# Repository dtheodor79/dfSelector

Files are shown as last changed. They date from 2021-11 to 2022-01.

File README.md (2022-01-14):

# Wireless DF selector
 The Wireless DF (WDF) selector allows users to boot an Amiga 500 from an internal or external drive. Instead of using a mechanical switch or multiple reset sequences to toggle between DF0 and DF1, WDF can be configured over a wireless connection. 
 
# Why bother?
Well, all this started because I don't like modifying my A500's precious case (like drilling to install a switch) 🙂. Also, I find more elegant using wireless commands to toggle between DF0 and DF1, than multiple resets 😎.
 
# Concept
The WDF concept is illustrated below: 

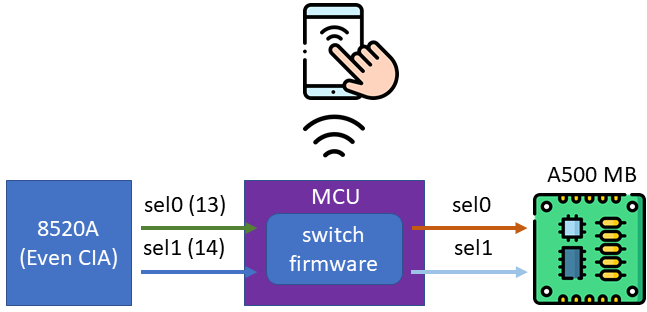
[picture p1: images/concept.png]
concept


Pins 13 (sel0) and 14 (sel1) from 8520A (even CIA) are connected to an MCU with wireless connection capability. Users can configure from an external device how these signals are forwarded to the A500 motherboard (MB), in order to select from which floppy drive the computer shall boot. 

# Demo video
Watch the video (https://youtu.be/IKIUbYo_S1U) 

# Implementation
The images below show three WDF 3D models that are implemented with an ESP32 MCU, enabling switch configuration over Bluetooth connections:

ESP32 "in front" of 8520A (click [here](https://www.pcbway.com/project/shareproject/Amiga_500_Wireless_DF_selector.html) to build one):

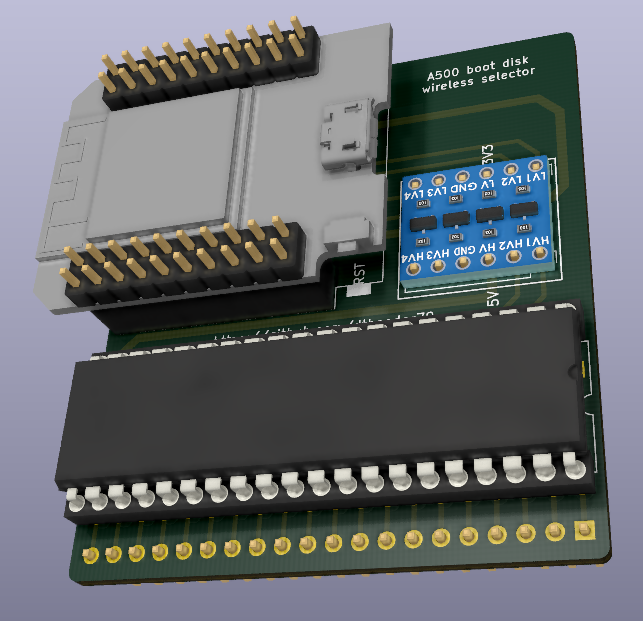
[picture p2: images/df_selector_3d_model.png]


ESP32 "behind" 8520A:

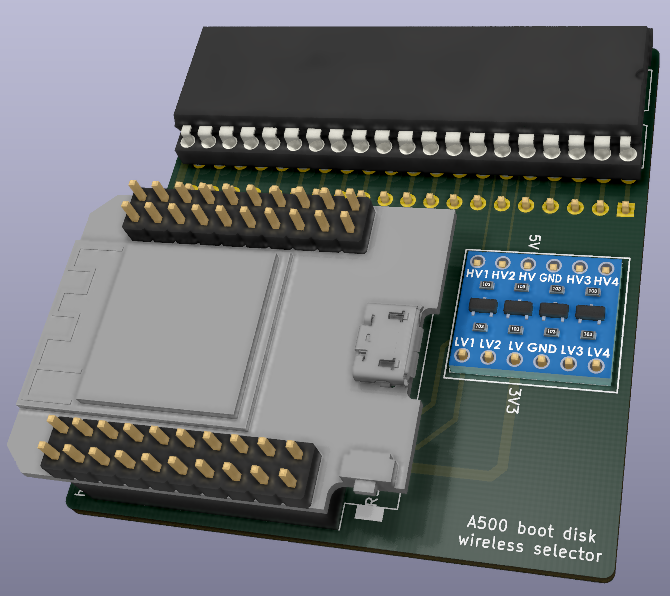
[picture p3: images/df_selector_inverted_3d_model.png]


ESP32 "stacked" on top of 8520A (click [here](https://www.pcbway.com/project/shareproject/Amiga_500_compact_wireless_DF_selector.html) to build one):

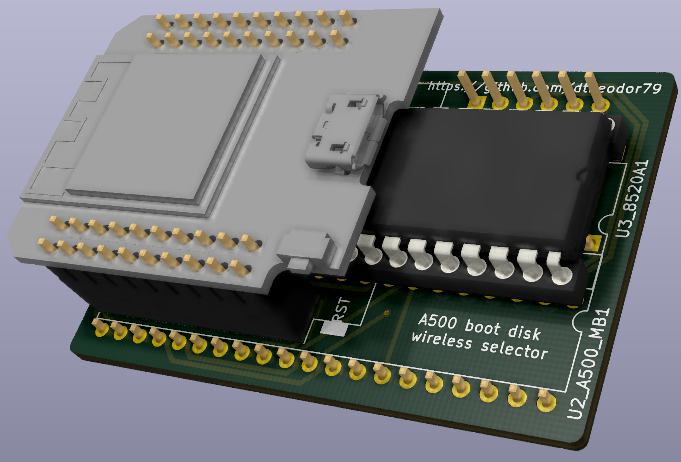
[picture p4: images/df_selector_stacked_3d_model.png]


A voltage convertor between 3.3V and 5V is used to allow communication between the ESP32 (3.3V) and the 8520A (5V). In addition, since the first WDF version (ESP32 "in front" of 8520A) is placed above the floppy ribbon cable connector of the A500, it requires long pin headers (such as the one below) to connect to the A500 MB:

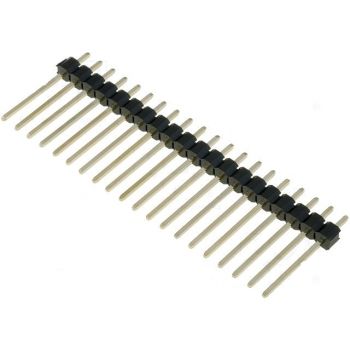
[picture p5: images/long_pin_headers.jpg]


# How to use the ESP32-based implementation
The current ESP32 firmware advertises a Bluetooth-enabled device with the name "A500 DF Selector". You will need another Bluetooth-enabled device to connect to the WDF and then send raw data for configuring the sel0 and sel1 switching. An easy way is to download a simple Bluetooth app to your smartphone that allows sending raw data to other devices. 

## Toggle DF1 as bootable:

* Make sure that there is no disk in DF0.
* Power-up the A500 and wait for few secs (e.g. 5).
* Scan for the "A500 DF Selector" device, and when found, connect to it.
* Send "df1".
* Power-down the A500 for a few secs.
* Power-up again, and now the A500 should boot from DF1.

## Toggle DF0 as bootable:

* Make sure that there is no disk (or adf image that will boot) in DF1.
* Power-up the A500 and wait for few secs (e.g. 5).
* Scan for the "A500 DF Selector" device, and when found, connect to it.
* Send "df0".
* Power-down the A500 for a few secs.
* Power-up again, and now the A500 should boot from DF0.

# Important notes
- All tests were carried out with a modified PC-floppy as DF0 and a Gotek emulator as DF1 (but jumper set to S0). As you can see in the demo video above, floppy selection could be done seamlessly without even restarting the A500 💣, by sending "df0" and "df1" commands when there was no floppy access. If you would like to try it, please be careful and always make sure before sending any command that there is no floppy access (don't blame me if there is any damage though 😛). 
- When DF0 is selected, the current firmware  
  - forwards sel0 (8520A) ➡️ sel0 (A500 MB)
  - sets sel1 (A500 MB) ➡️ HIGH
- When DF1 is selected, the current firmware  
  - forwards sel0 (8520A) ➡️ sel1 (A500 MB)
  - forwards sel1 (8520A) ➡️ sel0 (A500 MB)

Feel free to change how the firmware handles switching, so it suits to your configuration 😉.

# Pictures of the ESP32 implementation
Here are a few images of the final prototype on my A500.

WDF mounted above the floppy ribbon cable connector:

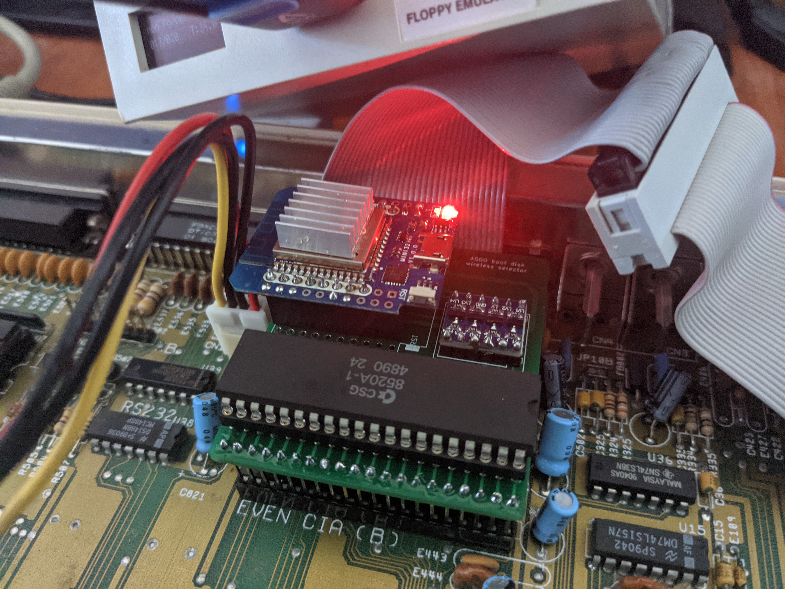
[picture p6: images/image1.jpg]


Loading Cannon Fodder from the Gotek emulator as DF1:

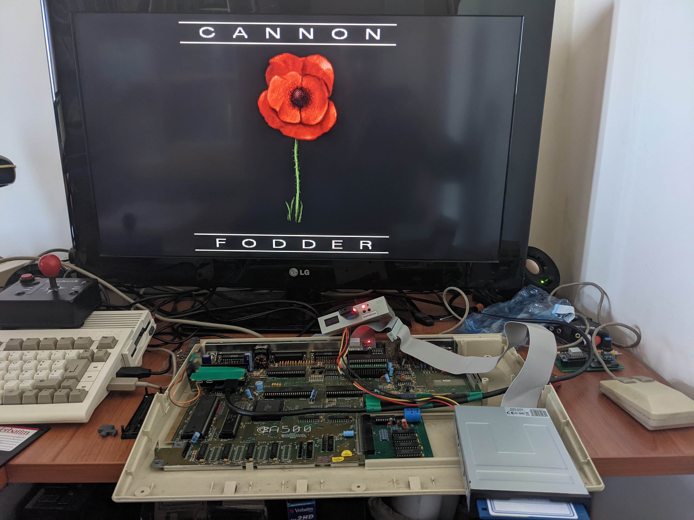
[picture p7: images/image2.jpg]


Another view of the WDF mounted above the floppy ribbon cable connector:

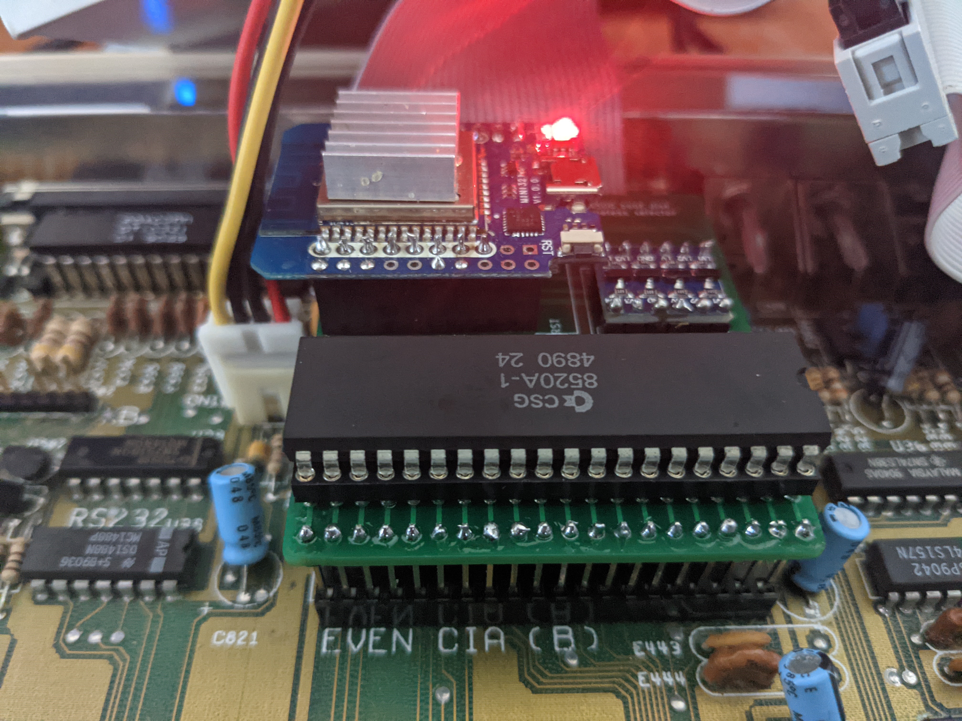
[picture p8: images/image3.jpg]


Gotek emulator connected externally:

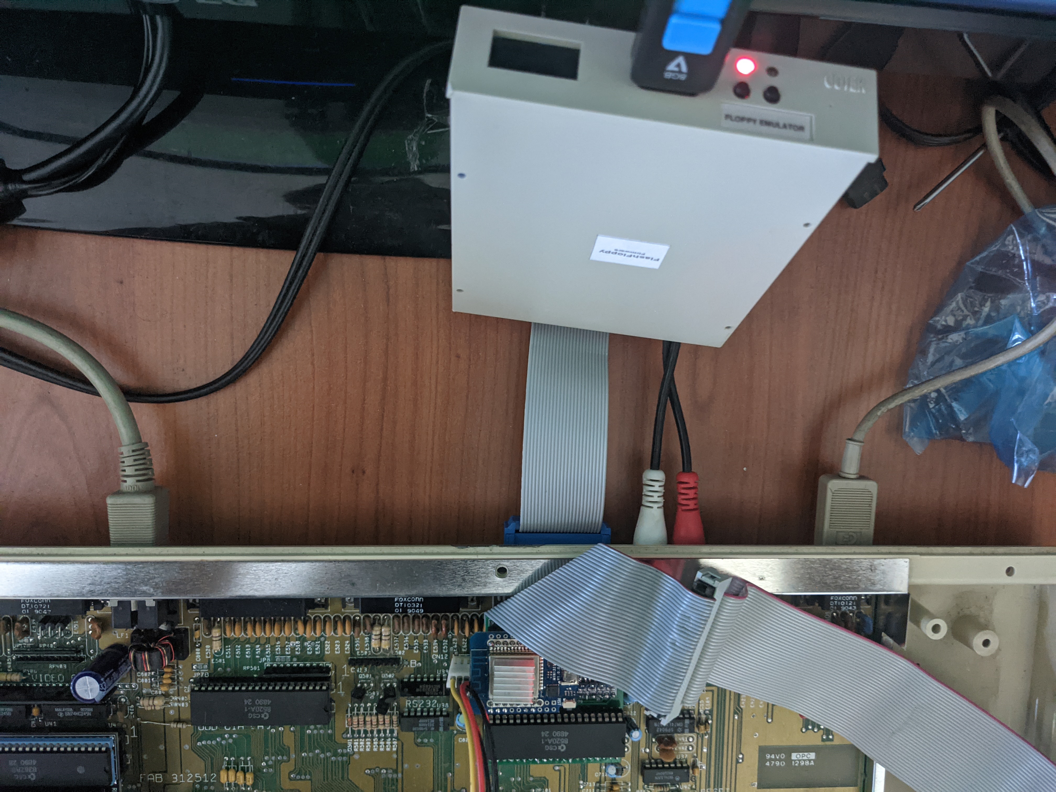
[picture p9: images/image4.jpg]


Hope you find it useful!! 😎

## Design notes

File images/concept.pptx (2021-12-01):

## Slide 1

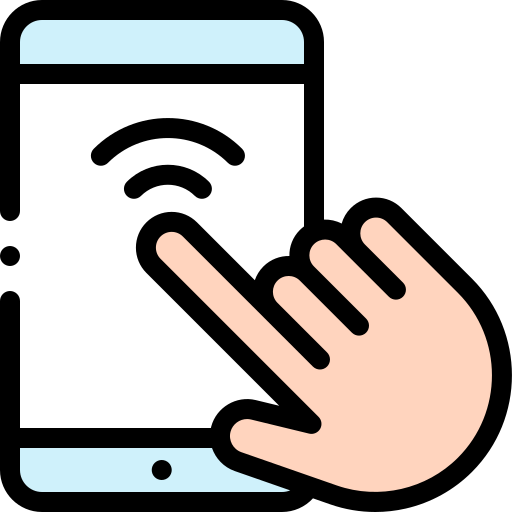
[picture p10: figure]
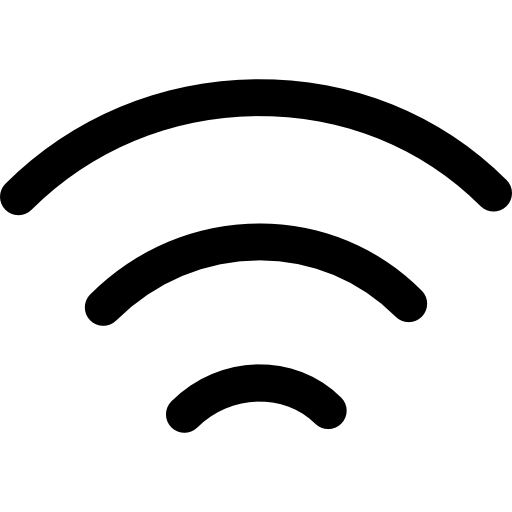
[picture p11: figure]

A500 MB

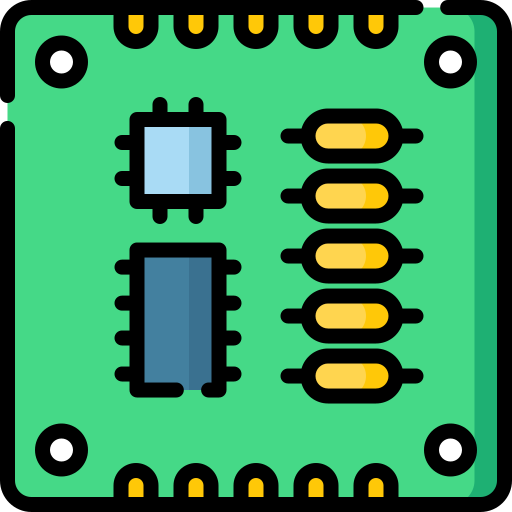
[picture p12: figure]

8520A
(Even CIA)

sel0 (13)

MCU

switch
firmware

sel0

sel1

sel1 (14)

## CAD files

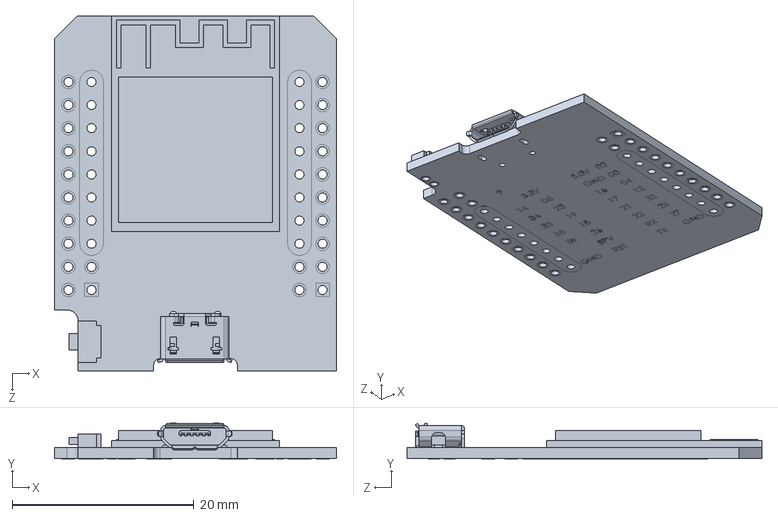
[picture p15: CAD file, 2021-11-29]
pcb/esp32 3d model/Wemos-Mini-D1-ESP32.SLDPRT
31.0 x 3.92 x 39.0 mm

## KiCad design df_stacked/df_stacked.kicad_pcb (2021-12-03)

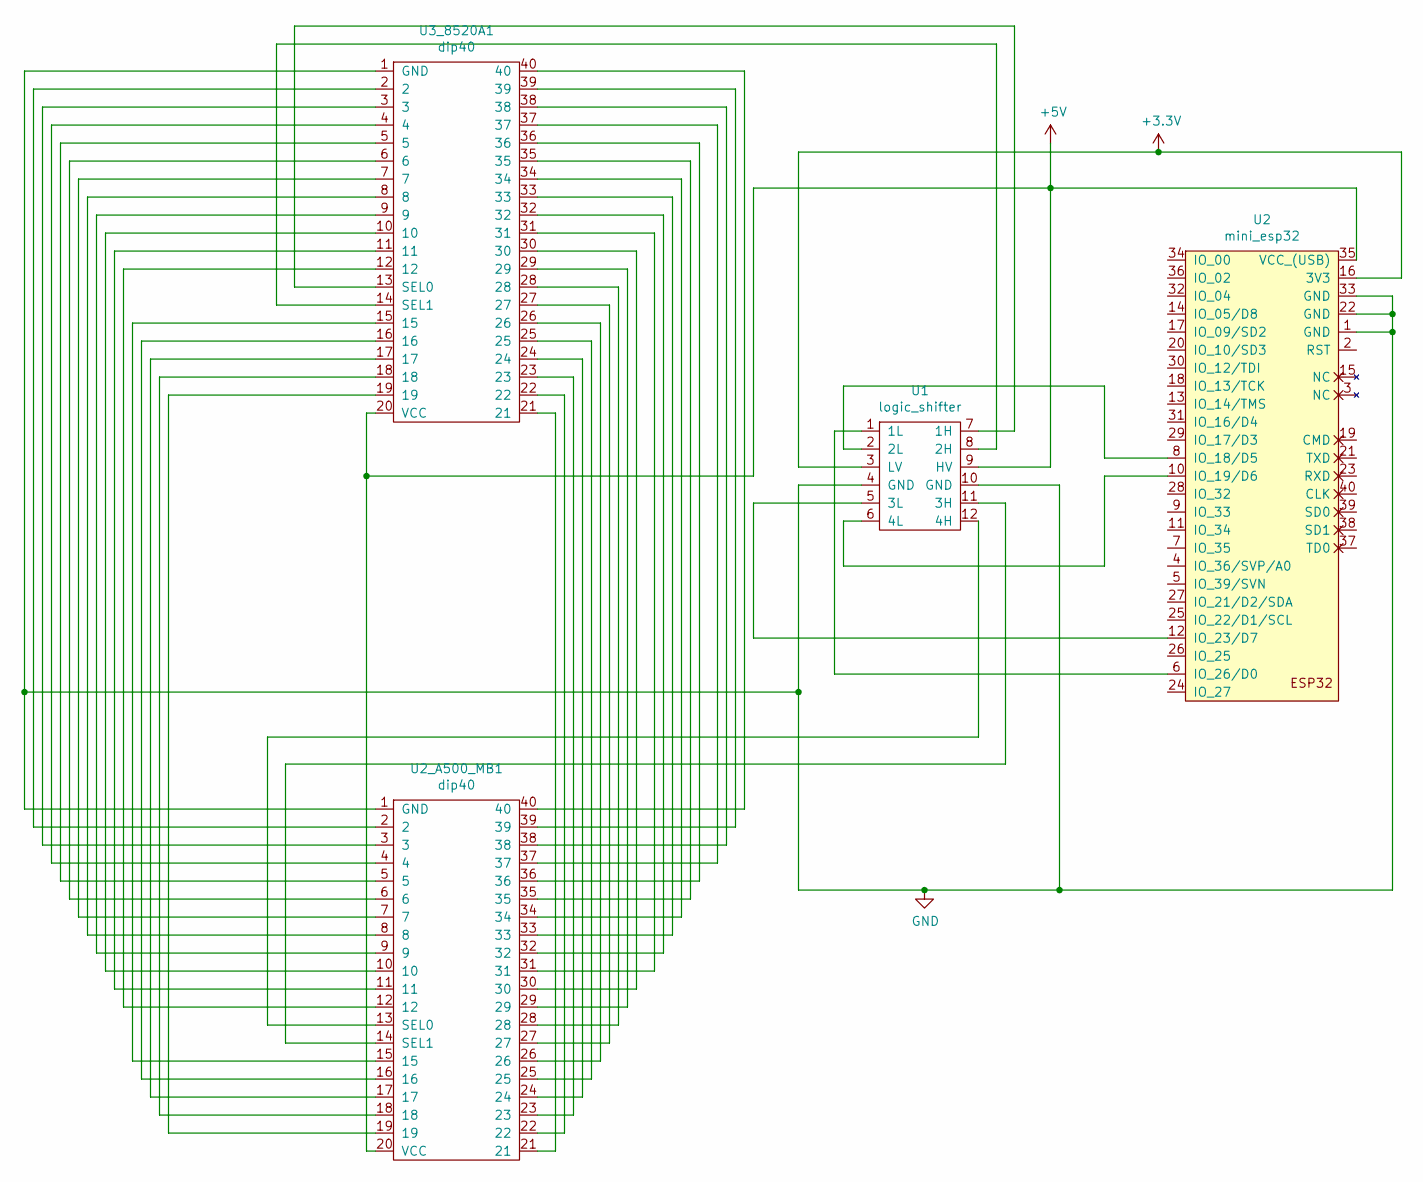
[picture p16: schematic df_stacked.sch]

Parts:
U1: logic_shifter; 4channel_logic_shifter
U2: mini_esp32; ESP32_mini
U2_A500_MB1, U3_8520A1: dip40; DIP-40_W15.24mm

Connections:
+3V3: U1.3 (LV), U2.16 (3V3)
+5V: U1.9 (HV), U2.35 (VCC_(USB)), U2_A500_MB1.20 (VCC), U3_8520A1.20 (VCC)
GND: U1.4 (GND), U1.10 (GND), U2.1 (GND), U2.22 (GND), U2.33 (GND), U2_A500_MB1.1 (GND), U3_8520A1.1 (GND)
unnamed: U1.1 (1L), U2.6 (IO_26/D0)
unnamed: U1.2 (2L), U2.8 (IO_18/D5)
unnamed: U1.5 (3L), U2.12 (IO_23/D7)
unnamed: U1.6 (4L), U2.10 (IO_19/D6)
unnamed: U1.7 (1H), U3_8520A1.13 (SEL0)
unnamed: U1.8 (2H), U3_8520A1.14 (SEL1)
unnamed: U1.11 (3H), U2_A500_MB1.14 (SEL1)
unnamed: U1.12 (4H), U2_A500_MB1.13 (SEL0)
unnamed: U2_A500_MB1.2, U3_8520A1.2
unnamed: U2_A500_MB1.3, U3_8520A1.3
unnamed: U2_A500_MB1.4, U3_8520A1.4
unnamed: U2_A500_MB1.5, U3_8520A1.5
unnamed: U2_A500_MB1.6, U3_8520A1.6
unnamed: U2_A500_MB1.7, U3_8520A1.7
unnamed: U2_A500_MB1.8, U3_8520A1.8
unnamed: U2_A500_MB1.9, U3_8520A1.9
unnamed: U2_A500_MB1.10, U3_8520A1.10
unnamed: U2_A500_MB1.11, U3_8520A1.11
unnamed: U2_A500_MB1.12, U3_8520A1.12
unnamed: U2_A500_MB1.15, U3_8520A1.15
unnamed: U2_A500_MB1.16, U3_8520A1.16
unnamed: U2_A500_MB1.17, U3_8520A1.17
unnamed: U2_A500_MB1.18, U3_8520A1.18
unnamed: U2_A500_MB1.19, U3_8520A1.19
unnamed: U2_A500_MB1.21, U3_8520A1.21
unnamed: U2_A500_MB1.22, U3_8520A1.22
unnamed: U2_A500_MB1.23, U3_8520A1.23
unnamed: U2_A500_MB1.24, U3_8520A1.24
unnamed: U2_A500_MB1.25, U3_8520A1.25
unnamed: U2_A500_MB1.26, U3_8520A1.26
unnamed: U2_A500_MB1.27, U3_8520A1.27
unnamed: U2_A500_MB1.28, U3_8520A1.28
unnamed: U2_A500_MB1.29, U3_8520A1.29
unnamed: U2_A500_MB1.30, U3_8520A1.30
unnamed: U2_A500_MB1.31, U3_8520A1.31
unnamed: U2_A500_MB1.32, U3_8520A1.32
unnamed: U2_A500_MB1.33, U3_8520A1.33
unnamed: U2_A500_MB1.34, U3_8520A1.34
unnamed: U2_A500_MB1.35, U3_8520A1.35
unnamed: U2_A500_MB1.36, U3_8520A1.36
unnamed: U2_A500_MB1.37, U3_8520A1.37
unnamed: U2_A500_MB1.38, U3_8520A1.38
unnamed: U2_A500_MB1.39, U3_8520A1.39
unnamed: U2_A500_MB1.40, U3_8520A1.40

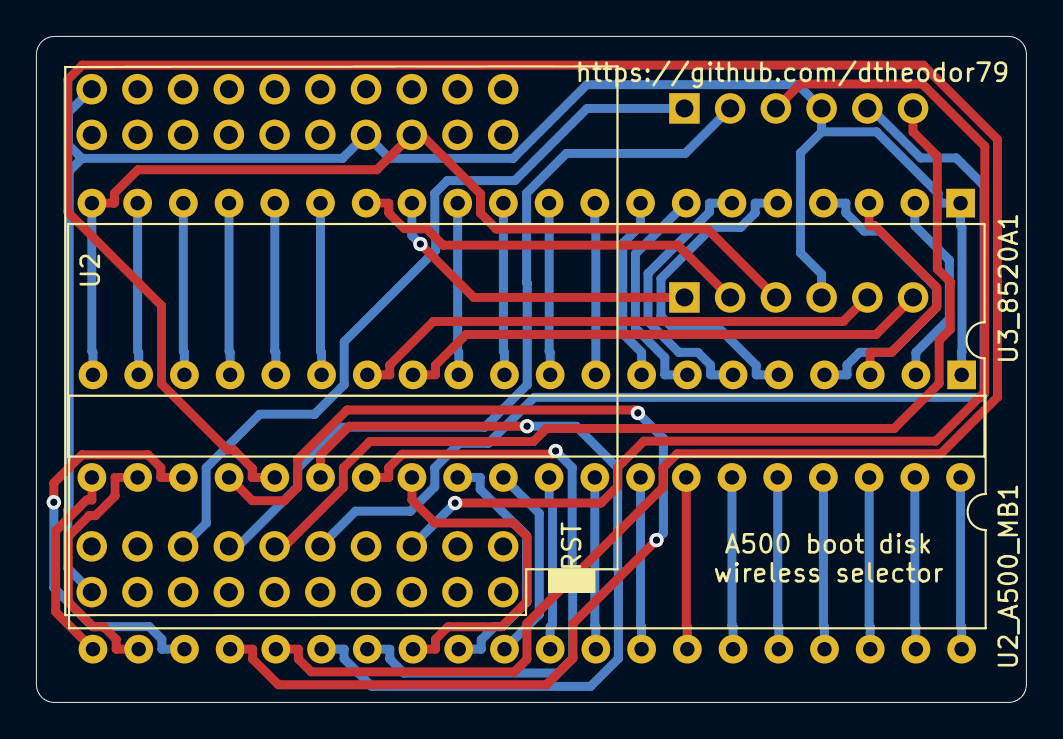
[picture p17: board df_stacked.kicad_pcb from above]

Board: 2 copper layers, 55.0 x 37.0 mm, 4 parts (1 on the bottom side), 47 nets.

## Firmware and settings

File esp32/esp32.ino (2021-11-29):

#include <HardwareSerial.h>
#include <BLEDevice.h>
#include <BLEUtils.h>
#include <BLEServer.h>
#include "driver/rtc_io.h"
#include <EEPROM.h>
#include <WiFi.h>

#define SERIAL_UART_BAUD 57600
#define DEVICE_SERVICE_UUID        "4fafc201-1fb5-459e-8fcc-c5c9c331914b"
#define DEVICE_CONFIG_CHARACTERISTIC_UUID "beb5483e-36e1-4688-b7f5-ea07361b26a8"

#define BT_DEVICE_ID "A500 DF Selector"

#define SET_DF1 "df1"
#define SET_DF0 "df0"

#define SELECTED_DRIVE_DF0 0
#define SELECTED_DRIVE_DF1 1

#define SEL0_IN GPIO_NUM_26
#define SEL1_IN GPIO_NUM_18
#define SEL0_OUT GPIO_NUM_19
#define SEL1_OUT GPIO_NUM_23

#define TIMEOUT_SEC 20
#define TIMEOUT_TIMER_ID 0

BLECharacteristic *bleConfigCharacteristic;
int selectedBootDrive = SELECTED_DRIVE_DF0;
//EEPROM ADDRESS MAP
const int selectedBootDriveEepromAddress = 0;
hw_timer_t * timer = NULL;
portMUX_TYPE timerMux = portMUX_INITIALIZER_UNLOCKED;
bool timeoutExpired = false, bleStarted = false;

void saveIntToEEPROM (int eepromAddress,int value) {  
  EEPROM.put(eepromAddress, value);    
  EEPROM.commit();
}

int loadIntFromEEPROM(int eepromAddress) {
  int readData;
  EEPROM.get(eepromAddress, readData);
  return readData;
}


void bleSendData(String text){
  Serial.println("bleSendData, text = " + text);
  bleConfigCharacteristic->setValue(text.c_str());  
  bleConfigCharacteristic->notify();
}

class MyBLECallbacks: public BLECharacteristicCallbacks {
  
  void onWrite(BLECharacteristic *pCharacteristic) {
   
    String uuidStr = pCharacteristic->getUUID().toString().c_str();
    Serial.println("MyBLECallbacks, uuidStr = " + uuidStr);
    String dataReceived = pCharacteristic->getValue().c_str();    
    Serial.println("MyBLECallbacks, dataReceived = " + dataReceived);    
    if (dataReceived.equals(SET_DF0)) {
      Serial.println("MyBLECallbacks, set df0 as boot drive.");    
      selectedBootDrive = SELECTED_DRIVE_DF0;
      saveIntToEEPROM(selectedBootDriveEepromAddress,selectedBootDrive);
    }
    else if (dataReceived.equals(SET_DF1)) {
      Serial.println("MyBLECallbacks, set df1 as boot drive.");    
      selectedBootDrive = SELECTED_DRIVE_DF1;
      saveIntToEEPROM(selectedBootDriveEepromAddress,selectedBootDrive);
    }
  }
};


class MyBLEServerCallbacks: public BLEServerCallbacks {
    void onConnect(BLEServer* pServer) {
      Serial.println("MyBLEServerCallbacks, onConnect");      
    };

    void onDisconnect(BLEServer* pServer) {
      Serial.println("MyBLEServerCallbacks, onDisconnect");            
    }
};

void stopBLE() {
  if (BLEDevice::getInitialized()) {
    Serial.println("stopBLE..");      
  
    BLEDevice::getAdvertising()->stop();    
    BLEDevice::deinit(false);  
  
    Serial.println(" done!");    
  }
}

void startBLE() {
  Serial.println("startBLE..");

  char *bleSSID = BT_DEVICE_ID;  
  BLEDevice::init(bleSSID);  

  BLEServer *bleServer = BLEDevice::createServer();
  bleServer->setCallbacks(new MyBLEServerCallbacks());

  BLEService *pService = bleServer->createService(DEVICE_SERVICE_UUID);    

  bleConfigCharacteristic = pService->createCharacteristic(
                                         DEVICE_CONFIG_CHARACTERISTIC_UUID,
                                         BLECharacteristic::PROPERTY_READ |
                                         BLECharacteristic::PROPERTY_WRITE
                                       );
  bleConfigCharacteristic->setCallbacks(new MyBLECallbacks());
  bleConfigCharacteristic->setValue(""); 
  
  pService->start();
  Serial.println("startBLE, pService ok");

  BLEAdvertising *pAdvertising = bleServer->getAdvertising();
  pAdvertising->start();

  Serial.println("startBLE done!");
}

void IRAM_ATTR onTimer() {
  portENTER_CRITICAL_ISR(&timerMux);  
  timeoutExpired = true;
  portEXIT_CRITICAL_ISR(&timerMux); 
}

void enableTimeoutTimer() {
  Serial.println("enableTimeoutTimer..");  
  timer = timerBegin(TIMEOUT_TIMER_ID, 80, true);
  timerAttachInterrupt(timer, &onTimer, true);
  timerAlarmWrite(timer, 1000000 * TIMEOUT_SEC, true);
  timerAlarmEnable(timer);
}

void setup() {
  Serial.begin(SERIAL_UART_BAUD);
  Serial.println("Starting...");
  
  WiFi.disconnect();
  WiFi.mode(WIFI_OFF);
  
  EEPROM.begin(512);   
  selectedBootDrive = loadIntFromEEPROM(selectedBootDriveEepromAddress);
  if ((selectedBootDrive != SELECTED_DRIVE_DF0) && (selectedBootDrive != SELECTED_DRIVE_DF1)) {
    selectedBootDrive = SELECTED_DRIVE_DF0;
  }
  Serial.println("selectedBootDrive = " + String(selectedBootDrive));
  
  pinMode(SEL0_OUT, OUTPUT);
  pinMode(SEL1_OUT, OUTPUT);
  pinMode(SEL0_IN, INPUT);
  pinMode(SEL1_IN, INPUT);  

  //enableTimeoutTimer();
}

void loop() {
  if (timeoutExpired) {
    stopBLE();
  }

  if (selectedBootDrive == SELECTED_DRIVE_DF1) {  //works
    digitalWrite(SEL0_OUT, digitalRead(SEL1_IN));     
    digitalWrite(SEL1_OUT, digitalRead(SEL0_IN));
  }
  else if (selectedBootDrive == SELECTED_DRIVE_DF0) {    //works
    digitalWrite(SEL1_OUT, HIGH);
    digitalWrite(SEL0_OUT, digitalRead(SEL0_IN));
  }

  if (!bleStarted) {
    bleStarted = true;
    startBLE();
  }
     
}

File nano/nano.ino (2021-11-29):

#define SEL0         5
#define SEL1         6

int sel0Value = 0,sel1Value = 0;

void setup() {
  Serial.begin(57600); 
  delay(10);
  Serial.println();
  Serial.println("Starting...");

}

void loop() {
  int sel0Value = digitalRead(SEL0);
  int sel1Value = digitalRead(SEL1);
  Serial.print("sel0:sel1: " + String(sel0Value) + String(sel1Value) + " ");
  if ((sel0Value == 0) && (sel1Value == 1)) {
    Serial.println("df0 selected!");
  }
  else if ((sel0Value == 1) && (sel1Value == 0)) {
    Serial.println("df1 selected!");
  }
  else {
    Serial.println("invalid selection");
  }
  delay(1000);
}

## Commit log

2021-12-02 added inverted df selector
    [df_selector-B_Cu.gbl, df_selector-B_Mask.gbs, df_selector-B_Paste.gbp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]
2021-12-03 added stacked pcb
    [df_selector.kicad_pcb, df_stacked.dsn, df_stacked.kicad_pcb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]
2021-12-03 added bom
    [BOM.xlsx, df_selector.kicad_pcb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]
